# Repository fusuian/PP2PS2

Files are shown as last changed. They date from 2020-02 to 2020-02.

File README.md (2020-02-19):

# Precision Pro to PlayStation2 Adapter

マイクロソフト製フライトスティック SideWinder Precision Pro を、SONY PlayStation2に接続するアダプタです。

アナログスティックの傾きは、デュアルショック２の左アナログスティックではなく、方向キーにパルスを加えて疑似アナログスティックにしています。
（タイトーメモリーズⅡ 下巻に収録されているナイトストライカーをスムーズにプレイするための仕様です）

## ハードウェア

アダプタ本体となるマイコンボードと電子部品をブレッドボードに組み付けます。
ブレッドボードの配線図は、PP2PS2_Breadboard.pdf をご覧ください。

 - ブレッドボード ハーフサイズ x1
 - マイコンボード Arduino Nano x1
 - 3ステートバッファIC TC74HC125AP x1
 - ジャンパワイヤ 適宜
 - Dサブ15ピン メスコネクタ (to Precision Pro) x1
 − PlayStation2 コントローラケーブル x1
 - USBバッテリ (アダプタ電源)

## ソフトウェア

Arduino IDEを使用して、PP2PS2 スケッチをArduino Nanoに書き込みます。

 - PP2PS2.ino           スケッチ本体
 - PrecisionPro.h       PrecisionProクラス
 - DualShock2Talker.cpp DualShock2Talker本体
 - DualShock2Talker.h   DualShock2Talkerクラス
 - PP2DS2Talker.h       PP2DS2Talkerクラス
 - PWM.h                PWMクラス
 - sw_data_t.h          sw_data_t 共用体
 - portmacro.h          digitalWrite に相当する、portOn/portOffマクロを定義

## 使用方法

アダプタボードに Precision Pro とゲーム機を接続したら、
USBバッテリをArduino Nanoに接続して、ゲーム機の電源を入れます。

Precision Pro のスティック・ボタンと、PlayStation2 のコントローラの対応は以下の通りです。

 - スティック        十字キー（疑似アナログ）
 - スティックひねり  なし
 - スロットル        なし

 - Fireボタン        ×ボタン cross
 - Topボタン         ○ボタン circle
 - Top Upボタン      △ボタン triangle
 - Top Downボタン    □ボタン square
 - HATスイッチ       十字キー

 - Aボタン           STARTボタン
 - Bボタン           R1ボタン
 - Cボタン           L1ボタン
 - Dボタン           SELECTボタン

## 参考

1. [MaZderMind/SidewinderInterface](https://github.com/MaZderMind/SidewinderInterface/tree/master/software) Precision Proの通信プロトコルについて、オシロスコープ画像つきで詳細に説明されています。union sw_data_t の定義を引用しています。
2. [PS2専用ローリングスイッチ](http://magicpuppet.org/rollingswitch.html) DualShock の通信仕様や Arduino によるエミュレートについて、詳細に説明されています。rolling_switch.ino より DualShock2 との通信部分を抜き出して、 DualShock2Talker クラスとして実装しています。

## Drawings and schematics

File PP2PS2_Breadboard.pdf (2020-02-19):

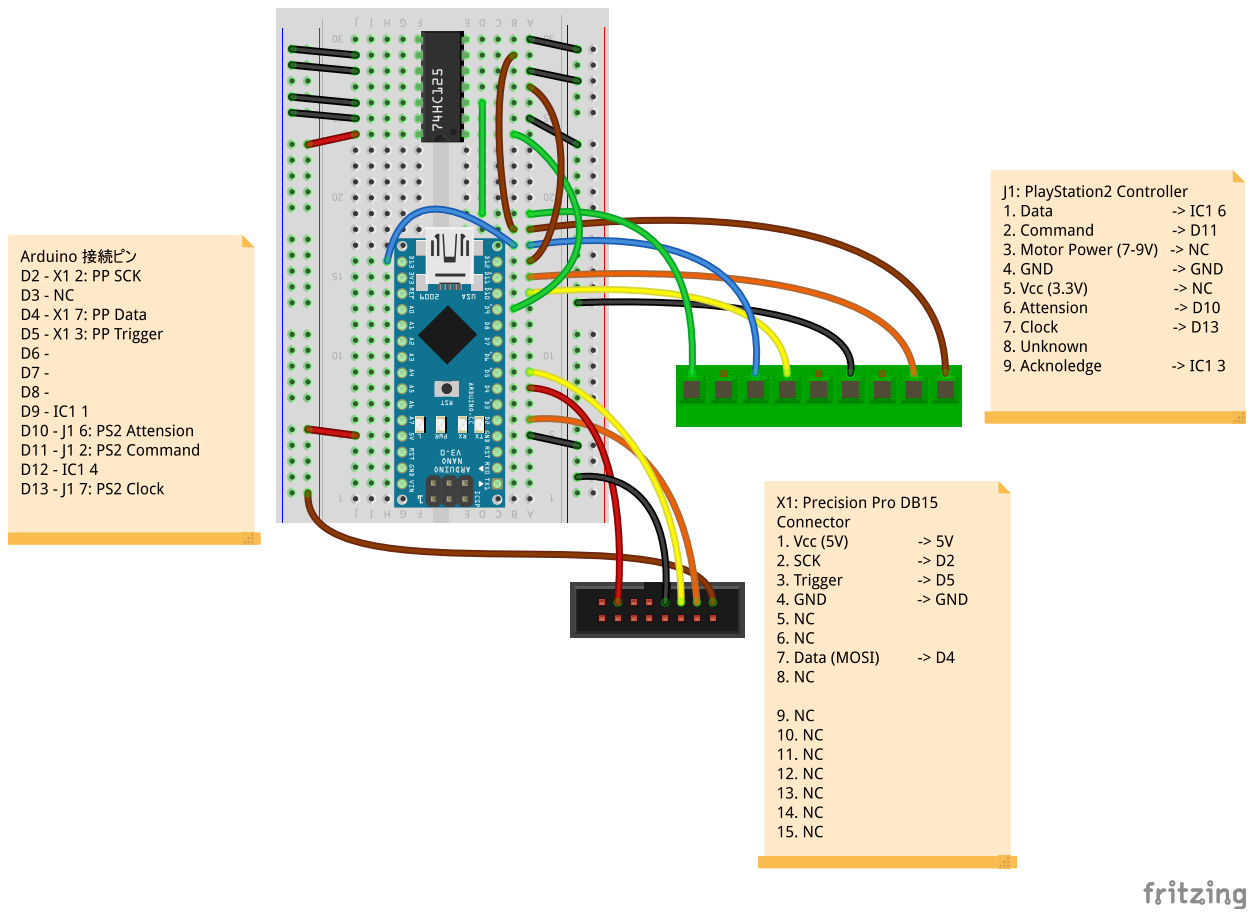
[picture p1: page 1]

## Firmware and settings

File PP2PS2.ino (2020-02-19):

// PP2PS2: SideWinder Precision Pro to PlayStation2 Adapter
//
// Copyright (c) 2019-2020 ASAHI,Michiharu
//
// Released under the MIT license
// see http://opensource.org/licenses/mit-license.php

#include <SPI.h>
#include <util/delay.h>
#include "PrecisionPro.h"
#include "PWM.h"
//#define DEBUG
#include "PP2DS2Talker.h"

// the center threshold of analog stick (x and y axis)
const int stick_center_threshold = 16;


// Arduino Pins for Precision Pro
int sck_pin     = 2;  // 割り込みピン(2 or 3)であること！
int mosi_pin    = 4;
int trigger_pin = 5;

// LED (optional)
const byte left_lite_pin  = A0;
const byte right_lite_pin = A1;


PrecisionPro * pp;
PP2DS2Talker * ds2talker;


void oneclock() {
    portOn(A5);
    *pdata++ = PIN(mosi_pin);
    portOff(A5);
}




void setup() {
    Serial.begin(115200);
    pinMode(A5, OUTPUT);
    pinMode(left_lite_pin, OUTPUT);
    pinMode(right_lite_pin, OUTPUT);

    pp = new PrecisionPro(trigger_pin, mosi_pin, sck_pin);
    pp->init();
    ds2talker = new PP2DS2Talker(pp);
    ds2talker->setup();
}



void loop() {
    if (ds2talker->isReady()) {
        pp->update();
        ds2talker->listened();

#if 0
        Serial.print(pp->x());
        Serial.print(", ");
        Serial.print(pp->y());
        Serial.println("");
#endif

        int x = (pp->x() / 4) - 0x80;
        if (abs(x) < stick_center_threshold) { x = 0; }
        if (x == 0) {
            ds2talker->set_right_key(0);
            ds2talker->set_left_key(0);
        } else if (x > 0) {
            ds2talker->set_right_key(x);
        } else {
            ds2talker->set_left_key(-x);
        }

        int y = (pp->y() / 4) - 0x80;
        if (abs(y) < stick_center_threshold) { y = 0; }
        if (y == 0) {
            ds2talker->set_up_key(0);
            ds2talker->set_down_key(0);
        } else if (y > 0) {
            ds2talker->set_down_key(y);
        } else {
            ds2talker->set_up_key(-y);
        }

        portWrite(left_lite_pin, DS_CIRCLE);
        portWrite(right_lite_pin, DS_CROSS);
    }
#ifdef DEBUG
    ds2talker_debug();
#endif
}

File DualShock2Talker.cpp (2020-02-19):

// DualShock2Talker.cpp: DualShock2 Emulator on Arduino
//
// Copyright (c) 2019-2020 ASAHI,Michiharu
//
// Based on Rolling switch for PS2
// Copyright (c) 2015 Kazumasa ISE
//
// Released under the MIT license
// http://opensource.org/licenses/mit-license.php

#include <SPI.h>
#include "DualShock2Talker.h"



void DualShock2Talker::setup() {
    isAnalogMode = false;
    isConfigMode = false;
    unknownFlag = false;

    // SPI setup
    SPI.setBitOrder(LSBFIRST);
    SPI.setDataMode(SPI_MODE3);
    SPCR &= ~(_BV(MSTR)); // Set as Slave
    SPCR |= _BV(SPE); // Enable SPI
    pinMode(SS, INPUT);
    pinMode(MOSI, INPUT);
    pinMode(MISO, OUTPUT);
    digitalWrite(MISO, HIGH);
    pinMode(SCK, INPUT);
    SPI.attachInterrupt();
    // ACK pin setup
    pinMode(ACK, OUTPUT);
    digitalWrite(ACK, HIGH);
}





void DualShock2Talker::debug() {
#ifdef DEBUG
    if (logCount == MAX_LOG_SIZE) {
        logCount = 0;
        int lfPos = -1;
        for (int i=0; i<MAX_LOG_SIZE; i++) {
            if (cmdLog[i] == LINE_FEED) {
                Serial.print("DAT: ");
                for (int j=lfPos+1; j<i; j++) {
                    Serial.print(datLog[j], HEX);
                    Serial.print(" ");
                }
                lfPos=i;
                Serial.println();
                Serial.print("CMD: ");
            } else {
                Serial.print(cmdLog[i], HEX);
                Serial.print(" ");
            }
        }
    }
#endif
}



#ifdef DEBUG
#define LINE_FEED 0xAA
#define MAX_LOG_SIZE 60
volatile byte cmdLog[MAX_LOG_SIZE] = {0};
volatile byte datLog[MAX_LOG_SIZE] = {0};
volatile int logCount = 0;
#endif


extern DualShock2Talker * ds2talker;


ISR(SPI_STC_vect) {
    static byte ID = 0x41;
    static byte CMD[CMD_BYTES] = {0};
    static byte cmdCount = 0;
    bool continueCom = false;
    CMD[cmdCount] = SPDR;
#ifdef DEBUG
    if (logCount < MAX_LOG_SIZE) {cmdLog[logCount++] = CMD[cmdCount];}
#endif
    const byte numOfCmd = 3+2*(ID & 0x0F);
    // Check CMD
    if (cmdCount == 0) {
        if (CMD[cmdCount] == 0x01) {
            continueCom = true;
        }
    } else if (cmdCount == 1) {
        if (CMD[cmdCount] == 0x01) {
            cmdCount = 0; // Reset count
            continueCom = true;
        } else if ((CMD[cmdCount] & 0x40) == 0x40) {
            continueCom = true;
        }
    } else if (cmdCount == 5) {
        if ((CMD[1] == READ_DATA) && (CMD[cmdCount] == 0x01)) {
            cmdCount = 0; // Reset count
        }
        continueCom = true;
    } else if (cmdCount < numOfCmd-1) {
        continueCom = true;
    }
#ifdef DEBUG
    if (!continueCom && (logCount < MAX_LOG_SIZE)) {cmdLog[logCount++] = LINE_FEED;}
#endif
    // Set next DAT
    cmdCount = continueCom ? cmdCount+1 : 0;
    const byte DAT = ds2talker->dat(CMD, cmdCount);
    if (cmdCount == 1) {ID = DAT;}
    SPDR = DAT;
#ifdef DEBUG
    if (logCount < MAX_LOG_SIZE) {datLog[logCount] = DAT;}
#endif
    if (continueCom) {
        ds2talker->acknowledge();
    } else {
        ds2talker->standby();
    }
}

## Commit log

2018-09-05 作成（ただし動かない）
2018-09-16 isPortが読み取れない問題を修正し、isPinに変更
2018-09-19 INT0_READシンボルによって、SPIを使わずに読み取り
2018-09-19 ボタン割り当てを変更
2018-09-19 ログの設定
2018-10-18 ボタンを正しく設定
2018-10-18 PS2コントローラへの書き出しと、Precision Proの読み取りのタイミングを制御
2018-10-18 タイトルの修正とDEBUGシンボルの削除、不要コメントの削除
2018-10-20 Pro Mini用のピン設定を削除
2018-10-20 PWMクラスを使ってアナログスティック入力を方向キーのパルスに変換（タイトーメモリーズのナイトストライカー対応）
2018-10-21 select, start, L2, R2ボタンの設定を変更
2018-10-30 配線図を追加
    [PP2PS2.fzz]
2018-11-03 FastRunningMedianでアナログスティック値の中央値をとる
2018-11-03 SPI読み込みのコードを削除、ピン番号を変更
2018-11-08 ピン番号チェックを追加
2018-11-15 ボタン配列を変更
2018-11-15 クロック読み取りをA5ピンで可視化
2018-11-15 ◯✕ボタンが押されたらLED点灯
2018-11-23 トリガー信号のあと、スティックのデータを読むウェイトを入れる
2018-11-23 DualShock2Talker.h/cppを分割。
2018-11-26 DualShock2Talkerクラスを作成
2018-11-27 移動量をシリアルに表示
2018-11-27 中央値をとらない
2020-02-16 FastRunningMedianを除く
2020-02-16 インデント等調整
2020-02-16 threshold 調整
2020-02-16 コピーライト追加
2020-02-19 sw_data_t.h を分割
2020-02-19 thresholdをstick_center_thresholdにリネーム
2020-02-19 PP2DS2Talker.h を分割
2020-02-19 SPI割り込みルーチンを DualShock2Talker.cpp に移動
2020-02-19 update()の関数本体をPWM.hに移動
2020-02-19 デバッグルーチンを削除
2020-02-19 不要な定義やコメントを削除
2020-02-19 コピーライトとライセンスを追加
2020-02-19 配線図を更新、PDF版の配線図を追加
    [PP2PS2.fzz]
2020-02-19 グローバル変数 read_pp と clock_msec を DualShock2Talker クラスに隠蔽
2020-02-19 配線図の電源系の間違いを修正
    [PP2PS2.fzz]
